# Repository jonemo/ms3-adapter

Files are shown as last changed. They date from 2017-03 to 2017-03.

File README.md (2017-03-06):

MS3 to Serial Port Adapter
==========================

What is this?
-------------

This repo contains a PCB design project including schematic, board layout, and component library.
The board is meant to provide an interface between three connectors:

* The DB15 connector (aka "VGA connector") attached to a Microscan MS3 barcode reader
* A DB9 connector plugged into the RS-232 "serial" port of a PC (or a USB-to-Serial converter or some other device with serial port)
* A 5.5mm center positive 5V DC power supply cable

When all three connectors are plugged in, the barcode reader is powered and can be communicated with from the PC.
For how to communicate with the barcode reader, please refer to Microscan's user manual or use [Microscan's ESP software](http://www.microscan.com/esp-easy-setup-program-software).
The Python library [microscan-driver](https://github.com/jonemo/microscan-driver) might be of use.

The files were created using Autodesk's Eagle 7.6.0.

Compatibility
-------------

I offer no guarantees that this PCB design works or
The board is almost certainly compatible with other Microscan barcode reader products, but it has only been tested with the MS3.

Sources
-------

The component library in this repo contains many footprints that are copied or modified from [Sparkfun's Eagle footprint library](https://github.com/sparkfun/SparkFun-Eagle-Libraries/).

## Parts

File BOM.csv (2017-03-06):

Part | Value | Device | Description | VENDOR | VENDOR_PN
D1 | PWR | LED5MM (GREEN) | LED (Generic) | Sparkfun | COM-12903
D2 | DATA OUT | LED5MM (BLUE) | LED (Generic) | Sparkfun | COM-12903
D3 | DATA IN | LED5MM (YELLOW) | LED (Generic) | Sparkfun | COM-12903
F1 | FUSE | FUSE |  | Sparkfun | COM-10166
J1 | TO PC | DB9-FEMALE | DB9 Connector | Sparkfun | PRT-00429
J2 | POWER | POWER_JACK | Power Jack Connector | Sparkfun | PRT-00119
J3 | TO MS3 | DB15-MALE |  | Digikey | A31927-ND
R1 |  | RESISTOR-AXIAL-0.3 | Generic Resistor Package | Sparkfun
R2 |  | RESISTOR-AXIAL-0.3 | Generic Resistor Package | Sparkfun
R3 |  | RESISTOR-AXIAL-0.3 | Generic Resistor Package | Sparkfun
S1 | PWRSWITCH | SWITCH-SPDT-PTH-11.6X4.0MM | Single Pole, Double Throw (SPDT) Switch | Sparkfun | COM-00102
S2 | TRIGGER | MOMENTARY-SWITCH-SPST-PTH-12MM | Momentary Switch (Pushbutton) - SPST | Sparkfun | COM-09190
S3 | RESET | MOMENTARY-SWITCH-SPST-PTH-12MM | Momentary Switch (Pushbutton) - SPST | Sparkfun | COM-09190

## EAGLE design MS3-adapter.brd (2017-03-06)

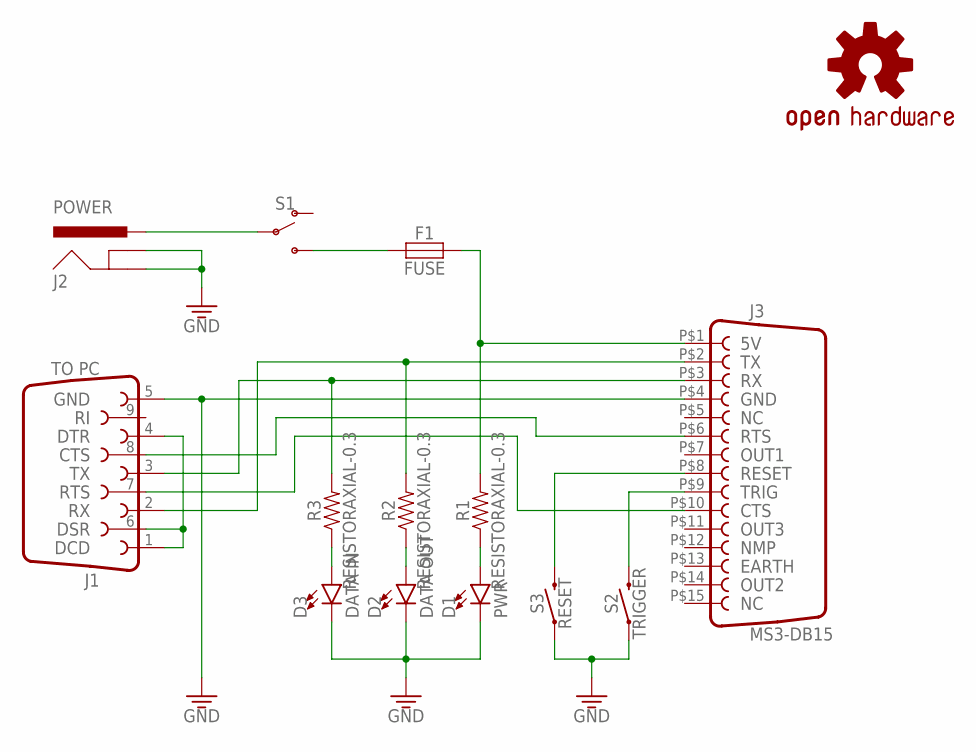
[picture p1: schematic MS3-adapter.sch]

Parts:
D1: PWR; LED_5MM
D2: DATA OUT; LED_5MM
D3: DATA IN; LED_5MM
F1: FUSE; FUSEHOLDER-PAIR-5MM
J1: TO PC; DB9-FEMALE
J2: POWER; POWER_JACK_PTH
J3: MS3-DB15; DB15-MALE
LOGO1: OSHW-LOGOS; OSHW-LOGO-S
R1, R2, R3: RESISTORAXIAL-0.3; AXIAL-0.3
S1: SWITCH-SPDT-PTH-11.6X4.0MM; SWITCH_SPDT_PTH_11.6X4.0MM
S2: TRIGGER; TACTILE_SWITCH_PTH_12MM
S3: RESET; TACTILE_SWITCH_PTH_12MM

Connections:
GND: D1.K (C), D2.K (C), D3.K (C), J1.5, J2.GND, J2.GNDBREAK, J3.P$4 (4), S2.1, S3.1
unnamed: J2.PWR, S1.2
unnamed: F1.P$1 (1), F1.P$2 (1), S1.3 (S)
unnamed: J1.3, J3.P$3 (3), R3.P$2 (2)
unnamed: J1.2, J3.P$2 (2), R2.P$2 (2)
unnamed: J1.1, J1.4, J1.6
unnamed: J1.7, J3.P$10 (10)
unnamed: J1.8, J3.P$6 (6)
unnamed: F1.P$3 (2), F1.P$4 (2), J3.P$1 (1), R1.P$2 (2)
unnamed: D2.A, R2.P$1 (1)
unnamed: D1.A, R1.P$1 (1)
unnamed: D3.A, R3.P$1 (1)
unnamed: J3.P$8 (8), S3.3 (2)
unnamed: J3.P$9 (9), S2.3 (2)

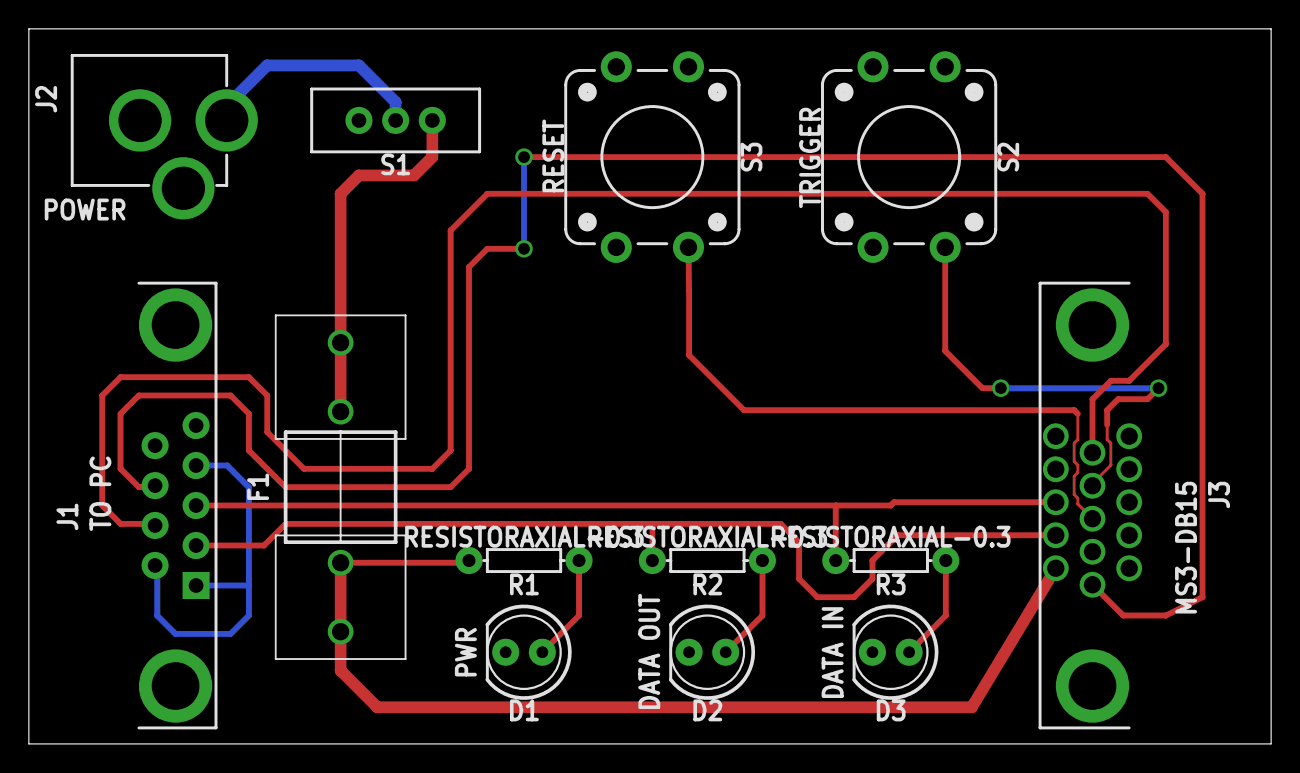
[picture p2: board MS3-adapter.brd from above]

Board: 2 copper layers, 86.0 x 49.5 mm, 14 parts (1 on the bottom side), 14 nets.
